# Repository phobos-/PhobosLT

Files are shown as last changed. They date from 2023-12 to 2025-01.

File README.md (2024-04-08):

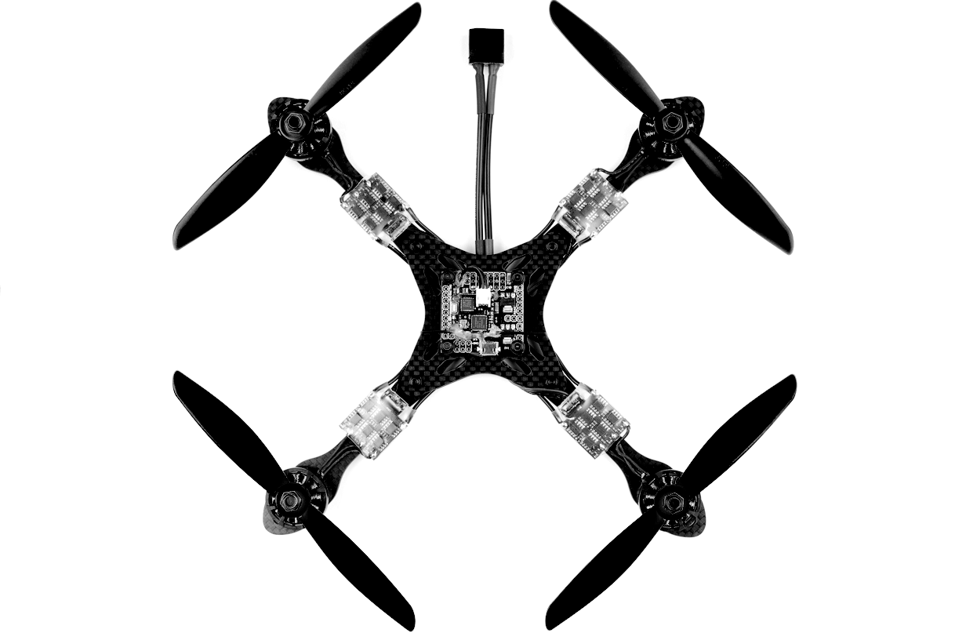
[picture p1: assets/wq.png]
PhobosLT
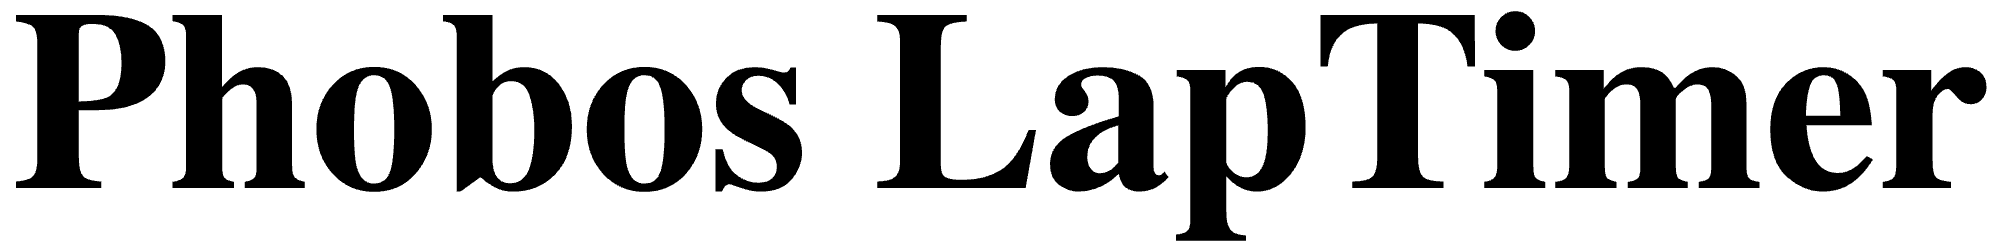
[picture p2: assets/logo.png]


 
# Support PhobosLT
**Affordable FPV single node Race Timing solution**

If you like this project you can support it by contributing to the codebase, testing and giving feedback, sharing new ideas and helping spread the PhobosLT gospel. You can also consider buying me a bubble tea or a beer, it will fuel me to make the project better!



# About

Phobos LapTimer (or PhobosLT) is a simple but mighty lap timing solution for 5.8GHz FPV pilots. It is designed for personal use and with small drones in mind (2 inch or less), but there is nothing against running it with bigger drones! It is a small standalone device that is self powered and communicates over WiFi with a phone, tablet or laptop. The goal of the project is to have a simple to use and small device that can be used anywhere whenever you want to do a whoop race practice session in your living room or at a local training venue with friends with no fuss.
Parts of the code are based on [RotorHazard](https://github.com/RotorHazard/RotorHazard) and [ExpressLRS](https://github.com/ExpressLRS/ExpressLRS). Big kudos to people behind these organizations, they are doing A LOT for the community and are shaping the future of FPV. If you don't know these projects yet and have some time, do check them out!

### Features

PhobosLT has the following features:
- Single node timing of 5.8GHz Analog, HDZero, Walksnail systems.
- Voice callouts, optionally including pilot name.
- Real time RSSI readout and calibration - allows for timing even in small spaces like a 16m^2 or 200 ft^2 room.
- 2 lap consecutive and 3 lap consecutive times and optional readouts on the fly (specially developed for [RaceGOW](https://www.racegow.com/)).
- Viewable lap history.
- Ability to set a minimal measurable lap time to avoid false positives.
- Configurable low voltage alarm.
- Small size, easy to build.
- Relatively cheap.
- No extra apps needed, self sufficient solution.

Future development plans:
- Flashing via WiFi or via web configurator.
- Custom hardware to minimize soldering.
- Integration with ExpressLRS and goggle VRXs to forward lap times to the OSD.
- Integration with RotorHazard to measure split times.
- Supporting multiple pilots at the same time at a cost of lower accuracy.

### How it works

The core of the project is an ESP32 board + an RX5808 module. ESP acts as a web server which serves a simple web page with all the configurations. Any device with WiFi connectivity and a web browser can be used to connect to it, configure the timer and measure lap times.

The lap timing happens by measuring the RSSI over time, filtering it and checking for peaks in the RSSI as the closer the drone is to the timer the higher the RSSI. Based on that we set up an `Enter RSSI` and `Exit RSSI` thresholds, that tell us when to cut a peak. The time between the enter and exit RSSI is then used to measure the time between the last peak and the current peak which is a lap.

Communication with the client happens over WiFi. The ESP32 sets up an access point and the client connects to it. RSSI is transmitted over a websocket to draw the RSSI graph in real time. Configuration, user interactions and events (like starting the timer, stopping, reporting a lap time) are done using rest calls.

The browser is leveraged to emit sounds or call out lap times using [articulate.js](https://github.com/acoti/articulate.js) library, but an optional (but recommended) beeper can be installed to the timer to also emit a sound every time a peak is detected or to alert e.g. when the timer battery voltage is low. 

# How to build one

### Hardware

To build a Phobos LapTimer you will need:
- An ESP32 breakout board, preferably with USB. The codebase is plug and play with `LilyGo T-ENERGY` which has a built in 1s 18650 Li-Ion cell slot and voltage sensing circuit out of the box. Supported boards:
    - LilyGo T-ENERGY - recommended.
    - LilyGo T-CELL - more expensive than the one above but has a charging circuit.
    - ESP32-DevKit - bare bones but cheap.
- An RX5808 VRx module with [SPI mod](https://sheaivey.github.io/rx5808-pro-diversity/docs/rx5808-spi-mod.html).
- A voltage supply of any sort - a battery, a powerbank, etc. It will depend on the ESP32 module used.
- (Optional) An LED of any color (+ a matching resistor to manage current).
- (Optional) A 3v3 to 5v buzzer WITH a generator (so active and not passive).

To connect the RX5808 to the ESP32 use below pinout table. Please note that +5v pin on the RX5808 should be connected to a 3v3 source to undervolt the RX5808 to get a better RSSI resolution and to help with cooling:
| ESP32 PIN | RX5880 |
| :--- |:---|
| 33 | RSSI |
| GND | GND |
| 19 | CH1 |
| 22 | CH2 |
| 23 | CH3 |
| 3V3 | +5V |

Optional but recommended LED, Buzzer and Battery voltage input pinout:
| ESP32 PIN | Peripheral |
| :--- |:---|
| 21 | LED anode (+) |
| 27 | Buzzer positive (+) |
| 35 | VBAT input MAX 3.3v (the code assumes a 1/2 voltage divider with a 1s Li-Ion  cell) |

You can find a connection diagram of the peripherals below. **For T-Energy and T-Cell you just need to connect the RX5808 and a buzzer.**

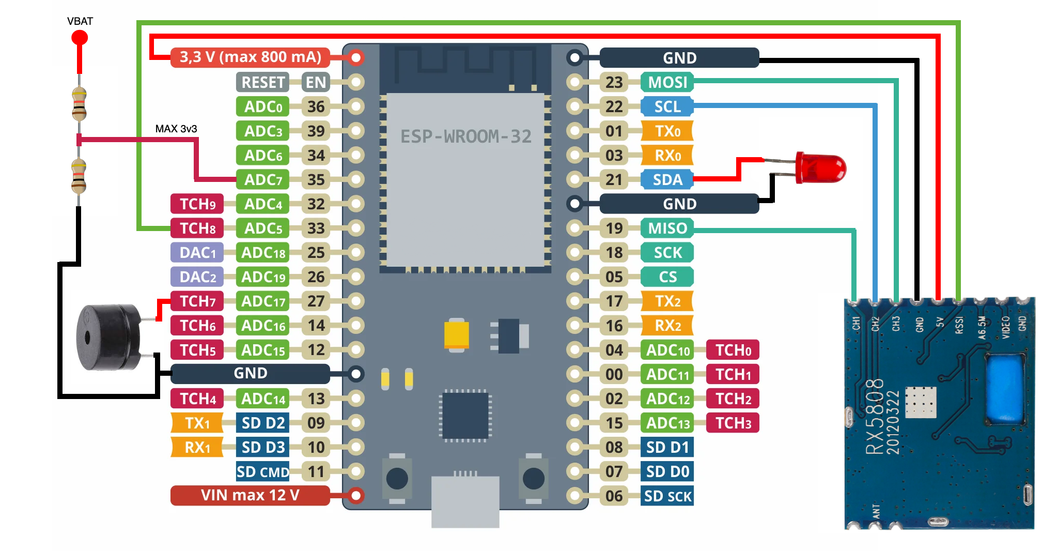
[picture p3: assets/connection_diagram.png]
Connection


Alternatively you can ask the community to build a timer for you. Ask around on discord!

### Firmware

Currently building the firmware happens via Visual Studio Code. The toolchain setup is exactly the same as for ExpressLRS, so if you already have an ExpressLRS toolchain set up and running, you should be good. The requirements to build the firmware are as follows:
- Visual Studio Code.
- PlatformIO.
- Git.

#### Toolchain setup

Perform these steps to set the toolchain up on your computer:
1. Download and install [vscode](https://code.visualstudio.com/).
2. Open vscode, and click on the `Extensions` icon in the toolbar on the right (see [Managing Extensions](https://code.visualstudio.com/docs/editor/extension-marketplace)).
3. In the search box, enter platformio, and install the extension (see the `pio install` [documentation](https://platformio.org/install/ide?install=vscode)).
4. Install [git](https://github.com/git-guides/install-git).

The last step before you can build the firmware is to clone this repository to your computer:
- In VSCode open the command palette (using `Cmd+Shift+P` on MacOS or `Ctrl+Shift+P` on Windows)
- Enter `Git: Clone`.
- Click it.
- Then, enter PhobosLT repo URL (can be found on top of the github page under the `Clone` button).
- Choose a folder where you want your copy of the repository to be located.

#### Building

To build the firmware, click the `PlatformIO` icon in the toolbar on the left, which will show the list of tasks. Now, select `Project Tasks`, expand `PhobosLT` -> `General` and select `Build`. You should see the result in the terminal after a few seconds (`Success`).

#### Flashing

Before attemtping to flash ensure there is a connection between the ESP32 and the computer via USB. Flashing is a two step process. First we need to flash the firmware, then the static file system image to the ESP32.

##### Step 1

To flash the firmware, click the `PlatformIO` icon in the toolbar on the left, which will show the list of tasks. Now, select `Project Tasks`, expand `PhobosLT` -> `General` and select `Upload`. You should see the result in the terminal (`Success`). Next, go to step 2.

##### Step 2

Select `Project Tasks`, expand `PhobosLT` -> `Platform` and select `Upload Filesystem Image`. Wait for the result in the terminal saying `Success`. That's it! Your timer is ready to use.

If something went wrong - please check the Terminal, too. It will contain at least a hint of what the issue is. Please ask the community for further help on discord!

#### 3D printed cases
[ESP-WROOM-32 case by porlock](https://makerworld.com/en/models/400720)

# Usage

This section is going to describe the usage and configuration of the timer. The app consists of 3 pages and is very easy to use!

### First connect

1. Turn on the timer, you should hear a short and a long beep.
2. Turn on your device and turn on WiFi.
3. Wait for it to discover a WiFi access point starting with `PhobosLT_xxxx`.
4. Click on it and type the password: `phoboslt`.
5. It should connect and open a browser window with the app for you. If it's not happening, open the browser and type `20.0.0.1`.
6. Voila!

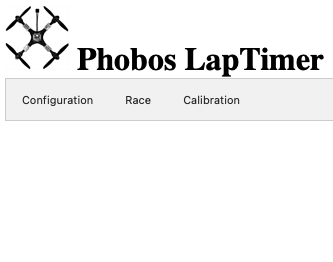
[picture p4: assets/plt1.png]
Homepage


### Configuration

To configure the timer you need to click on the `Configuration` button. You should be greeted with a screen similar to this:

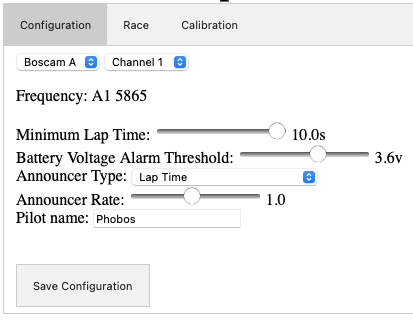
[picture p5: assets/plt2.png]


Below you can find all the config parameters and their description:

**Channel and Band** - set to the same Band and Channel as your drone. Supported Bands - A, B, E, Fatshark, RaceBand and LowBand, 8 channel each.
**Frequency** - this is a static field that will display the frequency based on the set Band and Channel.
**Minimum Lap Time** - you can set a minimum lap time that can be timed. This avoids false positives when you crash in the start gate, or when your track is very tight and you fly in close proximity to the timer multiple times during one lap.
**Battery Voltage Alarm Threshold** - sets a battery voltage alarm that will trigger once the desired voltage is reached. The range is between 2.5-4.2v.
**Announcer Type** - you have a few options on how you want your timer to report lap times:
- `None` is no sound at all.
- `Beep` will just emit a short beep on crossing to let you know it registered a lap.
- `Lap Time` will announce the lap time (including your pilot name if the **Pilot name** field is filled).
- `Two Consecutive Lap Time` will announce the two consecutive lap time.
- `Three Consecutive Lap Time` will announce the three consecutive lap time.

**Announcer Rate** - controls the speed of the announcer reading the lap time.
**Pilot Name** - when filled it will include pilot name when reading the times, e.g. `Pilot1 23.45`. It is useful when there is more than just one timer running at the same time. When practicing alone leave it empty.

**NOTE: Once configured make sure to save the configuration by clicking on the `Save Configuration` button, otherwise the changes will not take effect.**

### Calibration

Calibartion is a very important step and it needs to be done properly to ensure the timing happens correctly and every lap is counted by the timer.

To perform the calibration click on the `Calibration` button. You should be presented with two sliders and a graph representing the RSSI over time. You can think of RSSI as an inverse of the distance between the drone and the timer. The higher the RSSI the shorter the distance.

A node can be either `Crossing` or `Clear`. If a node is `Clear`, the timer believes a drone is not near the timer because the RSSI is low. If it is `Crossing`, the timer believes a drone is passing by the timer because the RSSI is high. A lap pass will be recorded once the `Crossing` is finished and the RSSI returns to `Clear` zone. We calibrate that by setting `Enter` and `Exit` RSSI thresholds.

A well calibrated timer will show the lap time when we have only one crossing when drone is the closest to the timer, e.g.:

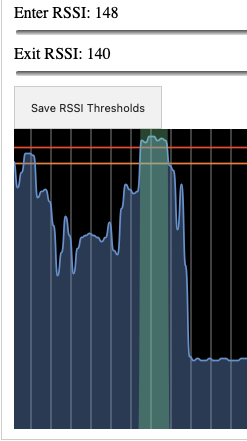
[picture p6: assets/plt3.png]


`Crossing` will always be marked in dark green, while `Clear` will be colored in blue.

To come up with good initial values for `Enter` and `Exit` RSSI perform these steps:
1. Turn on the timer and your drone, set it to the desired VTx power, wait 30 seconds for the VTx to reach its running temperature.
2. Place the drone at a distance of slightly more than one gate above the timer. 
3. Note the RSSI, deduct 2-5 points to be safe - that should be your `Enter RSSI`. 
4. Deduct another 8-10 points and set it as your `Exit RSSI`. 
5. **Click on `Save RSSI Thresholds` - otherwise the changes will not take effect.**

When flying with other pilots the RSSI readings might be lower due to all the noise generated by other VTxs on adjecent channels. A good practice is to lower both thresholds by a few points when flying with other pilots in the air.

### Race and lap management

The Race screen will allow you to start or stop a race and view and clear your lap times. Once clicked on the `Race` button a screen will change to this:

Race

Functions of the buttons:
- `Start Race` - click it to to start the countdown and signal the timer to start counting laps. 
- `Stop Race` - press it when you want to stop counting new laps. It does not clear the laps collected so far.
- `Clear Laps` - clears the laps on the screen, can be done when the race is running as well.

Once you run a few laps the screen will populate with lap times:

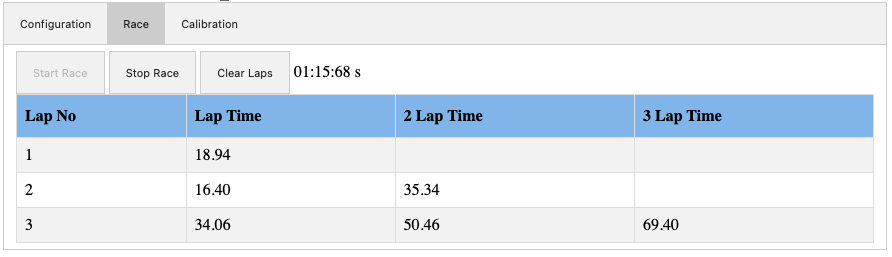
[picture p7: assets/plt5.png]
Race FInished


# Community

Join our [Discord](https://discord.gg/D3MgfvsnAw) channel for support and questions or just to hang out! Everyone is welcome!

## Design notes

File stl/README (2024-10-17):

I MODIFIED THIS VERSION SO YOU CAN PUT THE RECEIVER ON THE SIDE AND USE 6X3mm MAGNETS  
https://www.printables.com/model/88283-lilygo-t-energy-case

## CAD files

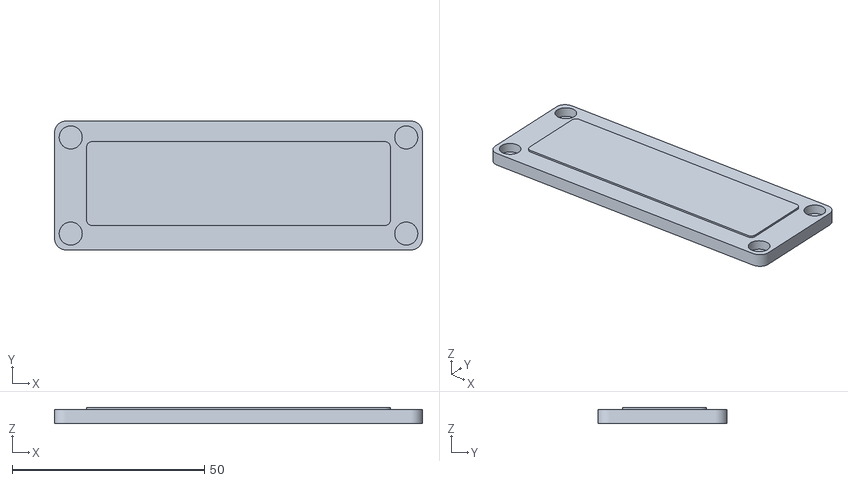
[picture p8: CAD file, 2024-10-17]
stl/T-Energy Thicc Bottom.stl
95.7 x 33.5 x 4.20

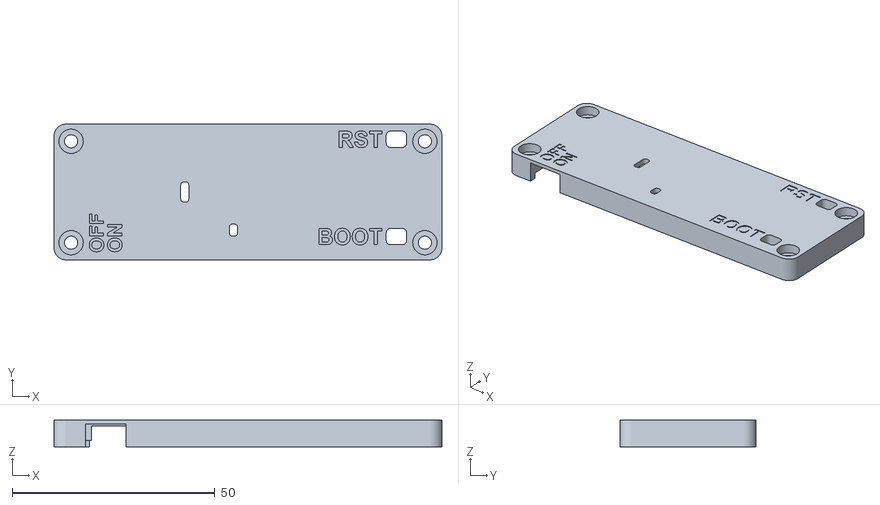
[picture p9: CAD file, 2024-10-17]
stl/T-Energy Thicc Top.stl
95.7 x 33.5 x 6.60

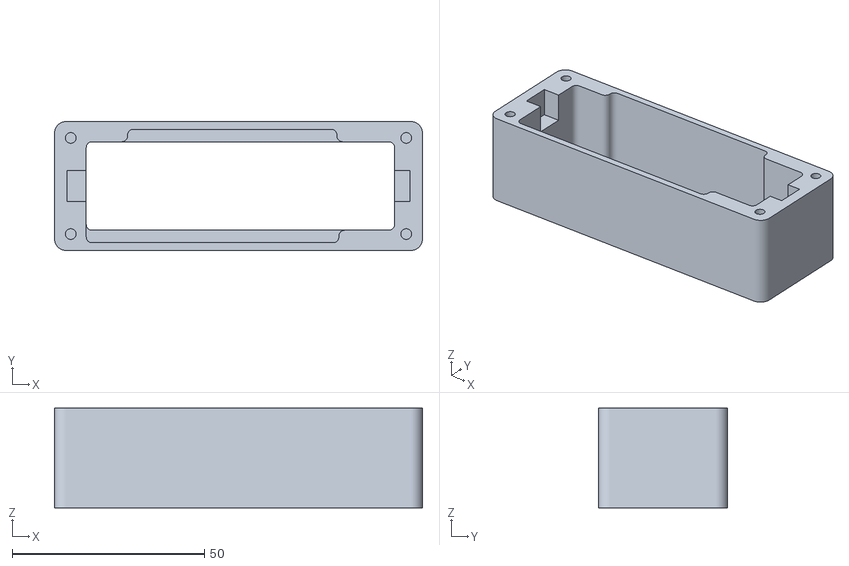
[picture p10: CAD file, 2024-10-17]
stl/T-Energy Thicc Middle.stl
95.7 x 33.5 x 26.0

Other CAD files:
stl/T-Go Energy Thicc v13.f3d

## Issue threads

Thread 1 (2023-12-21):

Unable to build firmware

caixiaohai0, 2023-12-21:
Processing PhobosLT (framework: arduino; platform: espressif32@5.2.0; board: esp32dev)
-----------------------------------------------------------------------------------------------------------------------------------------------------------------------------------------Verbose mode can be enabled via `-v, --verbose` option
CONFIGURATION: https://docs.platformio.org/page/boards/espressif32/esp32dev.html
PLATFORM: Espressif 32 (5.2.0) > Espressif ESP32 Dev Module
HARDWARE: ESP32 240MHz, 320KB RAM, 4MB Flash
DEBUG: Current (cmsis-dap) External (cmsis-dap, esp-bridge, esp-prog, iot-bus-jtag, jlink, minimodule, olimex-arm-usb-ocd, olimex-arm-usb-ocd-h, olimex-arm-usb-tiny-h, olimex-jtag-tiny, tumpa)
PACKAGES:
 - framework-arduinoespressif32 @ 3.20005.220925 (2.0.5)
 - tool-esptoolpy @ 1.40201.0 (4.2.1)
 - toolchain-xtensa-esp32 @ 8.4.0+2021r2-patch3
LDF: Library Dependency Finder -> https://bit.ly/configure-pio-ldf
LDF Modes: Finder ~ chain, Compatibility ~ soft
Found 44 compatible libraries
Scanning dependencies...
Dependency Graph
|-- ESPAsyncWebServer-esphome @ 3.0.0
|-- ArduinoJson @ 6.19.4
|-- DEBUG
|-- LED
|-- WEBSERVER
Building in release mode
Compiling .pio\build\PhobosLT\liba74\AsyncTCP-esphome\AsyncTCP.cpp.o
.pio/libdeps/PhobosLT/AsyncTCP-esphome/src/AsyncTCP.cpp:753:2: error: #else without #if
 #else
  ^~~~
.pio/libdeps/PhobosLT/AsyncTCP-esphome/src/AsyncTCP.cpp:755:2: error: #endif without #if
 #endif
  ^~~~~
.pio/libdeps/PhobosLT/AsyncTCP-esphome/src/AsyncTCP.cpp:1020: error: unterminated #if
 #if LWIP_IPV4 && LWIP_IPV6

.pio/libdeps/PhobosLT/AsyncTCP-esphome/src/AsyncTCP.cpp: In member function 'bool AsyncClient::connect(const char*, uint16_t)':
.pio/libdeps/PhobosLT/AsyncTCP-esphome/src/AsyncTCP.cpp:754:39: error: 'ip_addr_t' {aka 'struct ip_addr'} has no member named 'addr'; did you mean 'u_addr'?
         return connect(IPAddress(addr.addr), port);
                                       ^~~~
                                       u_addr
Compiling .pio\build\PhobosLT\FrameworkArduino\libb64\cdecode.c.o
Compiling .pio\build\PhobosLT\FrameworkArduino\libb64\cencode.c.o
Compiling .pio\build\PhobosLT\FrameworkArduino\main.cpp.o
Compiling .pio\build\PhobosLT\FrameworkArduino\stdlib_noniso.c.o
Compiling .pio\build\PhobosLT\FrameworkArduino\wiring_pulse.c.o
Compiling .pio\build\PhobosLT\FrameworkArduino\wiring_shift.c.o
*** [.pio\build\PhobosLT\liba74\AsyncTCP-esphome\AsyncTCP.cpp.o] Error 1
============================================================================== [FAILED] Took 11.06 seconds ==============================================================================

caixiaohai0, 2023-12-21:
When I try to build the firmware, it shows the error above, what step am I doing wrong?

phobos-, 2023-12-25:
Hey, thank you for spotting this. The problem was with AsyncTCP version that recently has been bumped to 2.1.0. I added an explicit dependency on 2.0.1 to fix the problem.

Here is the original issue:
https://github.com/esphome/issues/issues/5258

Here is my fix:
https://github.com/phobos-/PhobosLT/commit/ebac87fa705b17e784c25d2093556ea0d34bc4df

caixiaohai0, 2023-12-25:
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
The Discord invitation has expired, can you update it again?

phobos-, 2023-12-25:
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

done

Closed 2023-12-25.

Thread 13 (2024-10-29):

TTGO Cell, no download mode?

DexterGre, 2024-10-29:
Verbose mode can be enabled via `-v, --verbose` option
CONFIGURATION: https://docs.platformio.org/page/boards/espressif32/esp32dev.html
PLATFORM: Espressif 32 (6.9.0) > Espressif ESP32 Dev Module
HARDWARE: ESP32 240MHz, 320KB RAM, 4MB Flash
DEBUG: Current (cmsis-dap) External (cmsis-dap, esp-bridge, esp-prog, iot-bus-jtag, jlink, minimodule, olimex-arm-usb-ocd, olimex-arm-usb-ocd-h, olimex-arm-usb-tiny-h, olimex-jtag-tiny, tumpa)
PACKAGES:
 - framework-arduinoespressif32 @ 3.20017.0 (2.0.17)
 - tool-esptoolpy @ 1.40501.0 (4.5.1)
 - tool-mkfatfs @ 2.0.1
 - tool-mklittlefs @ 1.203.210628 (2.3)
 - tool-mkspiffs @ 2.230.0 (2.30)
 - toolchain-xtensa-esp32 @ 8.4.0+2021r2-patch5
LDF: Library Dependency Finder -> https://bit.ly/configure-pio-ldf
LDF Modes: Finder ~ chain, Compatibility ~ soft
Found 45 compatible libraries
Scanning dependencies...
Dependency Graph
|-- ESPAsyncWebServer-esphome @ 3.2.2
|-- ArduinoJson @ 7.2.0
|-- AsyncTCP-esphome @ 2.1.4
|-- DEBUG
|-- LED
|-- WEBSERVER
Building in release mode
Retrieving maximum program size .pio\build\PhobosLT\firmware.elf
Checking size .pio\build\PhobosLT\firmware.elf
Advanced Memory Usage is available via "PlatformIO Home > Project Inspect"
RAM:   [=         ]  14.8% (used 48384 bytes from 327680 bytes)
Flash: [=======   ]  70.0% (used 917993 bytes from 1310720 bytes)
Configuring upload protocol...
AVAILABLE: cmsis-dap, esp-bridge, esp-prog, espota, esptool, iot-bus-jtag, jlink, minimodule, olimex-arm-usb-ocd, olimex-arm-usb-ocd-h, olimex-arm-usb-tiny-h, olimex-jtag-tiny, tumpa
CURRENT: upload_protocol = esptool
Looking for upload port...
Auto-detected: COM6
Uploading .pio\build\PhobosLT\firmware.bin
esptool.py v4.5.1
Serial port COM6
Connecting......................................

A fatal error occurred: Failed to connect to ESP32: Wrong boot mode detected (0x17)! The chip needs to be in download mode.
For troubleshooting steps visit: https://docs.espressif.com/projects/esptool/en/latest/troubleshooting.html
*** [upload] Error 2
========================================================================================= [FAILED] Took 17.21 seconds =========================================================================================

Environment    Status    Duration
-------------  --------  ------------
PhobosLT       FAILED    00:00:17.211
==================================================================================== 1 failed, 0 succeeded in 00:00:17.211 ====================================================================================

What do in have to press? Pressing RST didnt work. There is no boot buton on the TTGO T-CELL.

DexterGre, 2024-10-31:
my bad ... short GPIO0 with GND and then Press reset

Closed 2024-11-07.

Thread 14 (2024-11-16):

[BUG] Every 50th lap time is incorrect

Jaz7Mutant, 2024-11-16:
I've noticed that every 50th lap is approximately 1,000,000 seconds. You can see it in my run here.
[Phobos LapTimer.pdf](https://github.com/user-attachments/files/17787186/Phobos.LapTimer.pdf)

FernandoRangel, 2024-12-15:
> I've noticed that every 50th lap is approximately 1,000,000 seconds. You can see it in my run here. [Phobos LapTimer.pdf](https://github.com/user-attachments/files/17787186/Phobos.LapTimer.pdf)

I fixed it by changing this line
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

phobos-, 2025-01-13:
the fix is merged to master, closing this.

Closed 2025-01-13.

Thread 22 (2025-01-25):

SpeechSynthesis api doesn't work on mobile browser when it is not triggered directly by user

aikidistas, 2025-01-25:
Updated mobile browser policies disabled voice generated automatically by code without user input.
From now on we can't call SpeechSynthesis.speak directly from code that is not initiated by user click, like previously it was used by events.
Added "Enable voice" button which is calling articulate.js speak (which internally call SpeechSynthesis.speak.
Workaround pass text to speak to main code initiated by user with "enable voice" button.

Created pull request to fix this issue.
https://github.com/phobos-/PhobosLT/pull/21

phobos-, 2025-01-27:
Thank you! This is merged now, enjoy.

Closed 2025-01-27.

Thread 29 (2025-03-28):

Build failure due to package AsyncWebServer

orevron, 2025-03-28:
Trying to build the project (no matter which platform I'm trying to build for wether it is PhobosLT default of S3) I'm getting the same error as the following:

```
Processing ESP32S3 (framework: arduino; platform: espressif32@6.9.0; board: esp32-s3-devkitc-1)
---------------------------------------------------------------------------------------------------------------------------------------------------------------------------------------
Library Manager: Installing git+https://github.com/mkfrey/AsyncTCP#kconfig_queue_size
git version 2.39.5 (Apple Git-154)
Cloning into '/Users/oevron/.platformio/.cache/tmp/pkg-installing-ftwaudvs'...
remote: Enumerating objects: 23, done.
remote: Counting objects: 100% (23/23), done.
remote: Compressing objects: 100% (21/21), done.
remote: Total 23 (delta 0), reused 10 (delta 0), pack-reused 0 (from 0)
Receiving objects: 100% (23/23), 19.40 KiB | 19.40 MiB/s, done.
Library Manager: AsyncTCP@1.1.1+sha.7855e2c has been installed!
Library Manager: Installing mathieucarbou/ESPAsyncWebServer @ ^3.3.21
Unpacking  [####################################]  100%
Library Manager: ESPAsyncWebServer@3.6.0 has been installed!
Library Manager: Resolving dependencies...
Library Manager: Installing mathieucarbou/AsyncTCP @ ^3.3.2
Unpacking  [####################################]  100%
Library Manager: AsyncTCP@3.3.2 has been installed!
Library Manager: Installing bblanchon/ArduinoJson @ 7.2.0
Unpacking  [####################################]  100%
Library Manager: ArduinoJson@7.2.0 has been installed!
Library Manager: Installing ayushsharma82/ElegantOTA @ ^3.1.6
Unpacking  [####################################]  100%
Library Manager: ElegantOTA@3.1.7 has been installed!
Library Manager: Resolving dependencies...
Library Manager: Installing esp32async/ESPAsyncWebServer @ ^3.7.3
Unpacking  [####################################]  100%
Library Manager: ESPAsyncWebServer@3.7.4 has been installed!
Library Manager: Resolving dependencies...
Library Manager: Installing ESP32Async/AsyncTCP @ ^3.3.8
Unpacking  [####################################]  100%
Library Manager: AsyncTCP@3.3.8 has been installed!
Verbose mode can be enabled via `-v, --verbose` option
CONFIGURATION: https://docs.platformio.org/page/boards/espressif32/esp32-s3-devkitc-1.html
PLATFORM: Espressif 32 (6.9.0) > Espressif ESP32-S3-DevKitC-1-N8 (8 MB QD, No PSRAM)
HARDWARE: ESP32S3 240MHz, 320KB RAM, 8MB Flash
DEBUG: Current (esp-builtin) On-board (esp-builtin) External (cmsis-dap, esp-bridge, esp-prog, iot-bus-jtag, jlink, minimodule, olimex-arm-usb-ocd, olimex-arm-usb-ocd-h, olimex-arm-usb-tiny-h, olimex-jtag-tiny, tumpa)
PACKAGES:
 - framework-arduinoespressif32 @ 3.20017.241212+sha.dcc1105b
 - tool-esptoolpy @ 1.40501.0 (4.5.1)
 - toolchain-riscv32-esp @ 8.4.0+2021r2-patch5
 - toolchain-xtensa-esp32s3 @ 8.4.0+2021r2-patch5
LDF: Library Dependency Finder -> https://bit.ly/configure-pio-ldf
LDF Modes: Finder ~ chain, Compatibility ~ strict
Found 49 compatible libraries
Scanning dependencies...
Dependency Graph
|-- AsyncTCP @ 1.1.1+sha.7855e2c
|-- ESPAsyncWebServer @ 3.6.0
|-- ArduinoJson @ 7.2.0
|-- ElegantOTA @ 3.1.7
|-- DEBUG
|-- LED
|-- WEBSERVER
Building in release mode
Compiling .pio/build/ESP32S3/src/main.cpp.o
Building .pio/build/ESP32S3/bootloader.bin
Generating partitions .pio/build/ESP32S3/partitions.bin
esptool.py v4.5.1
Creating esp32s3 image...
Merged 1 ELF section
Successfully created esp32s3 image.
Compiling .pio/build/ESP32S3/lib44a/AsyncTCP@src-08944e2265d70e4bf415e06a141519af/AsyncTCP.cpp.o
Compiling .pio/build/ESP32S3/lib73a/FS/FS.cpp.o
Compiling .pio/build/ESP32S3/lib73a/FS/vfs_api.cpp.o
Compiling .pio/build/ESP32S3/lib57d/WiFi/WiFi.cpp.o
Compiling .pio/build/ESP32S3/lib57d/WiFi/WiFiAP.cpp.o
Compiling .pio/build/ESP32S3/lib57d/WiFi/WiFiClient.cpp.o
Compiling .pio/build/ESP32S3/lib57d/WiFi/WiFiGeneric.cpp.o
Compiling .pio/build/ESP32S3/lib57d/WiFi/WiFiMulti.cpp.o
Compiling .pio/build/ESP32S3/lib57d/WiFi/WiFiSTA.cpp.o
Compiling .pio/build/ESP32S3/lib57d/WiFi/WiFiScan.cpp.o
Compiling .pio/build/ESP32S3/lib57d/WiFi/WiFiServer.cpp.o
In file included from lib/WEBSERVER/webserver.h:1,
                 from src/main.cpp:3:
.pio/libdeps/ESP32S3/ESPAsyncWebServer/src/ESPAsyncWebServer.h: In member function 'tcp_state AsyncWebServer::state() const':
.pio/libdeps/ESP32S3/ESPAsyncWebServer/src/ESPAsyncWebServer.h:1107:50: error: passing 'const AsyncServer' as 'this' argument discards qualifiers [-fpermissive]
     return static_cast<tcp_state>(_server.status());
                                                  ^
In file included from .pio/libdeps/ESP32S3/ESPAsyncWebServer/src/ESPAsyncWebServer.h:19,
                 from lib/WEBSERVER/webserver.h:1,
                 from src/main.cpp:3:
.pio/libdeps/ESP32S3/AsyncTCP@src-08944e2265d70e4bf415e06a141519af/src/AsyncTCP.h:202:13: note:   in call to 'uint8_t AsyncServer::status()'
     uint8_t status();
             ^~~~~~
Archiving .pio/build/ESP32S3/lib44a/libAsyncTCP@src-08944e2265d70e4bf415e06a141519af.a
Compiling .pio/build/ESP32S3/lib57d/WiFi/WiFiUdp.cpp.o
Archiving .pio/build/ESP32S3/lib73a/libFS.a
*** [.pio/build/ESP32S3/src/main.cpp.o] Error 1
Indexing .pio/build/ESP32S3/lib44a/libAsyncTCP@src-08944e2265d70e4bf415e06a141519af.a
Indexing .pio/build/ESP32S3/lib73a/libFS.a
============================================================================= [FAILED] Took 6.81 seconds =============================================================================

Environment    Status    Duration
-------------  --------  ------------
ESP32S3        FAILED    00:00:06.809
======================================================================== 1 failed, 0 succeeded in 00:00:06.809 ========================================================================
```

Tried to resolve this issue by casting the return value of the `tcp_state` function in the package code, build was successful but then a crash happen in runtime when ever a client is connected to the hotspot.

Can you help me resolve this issue?

Thanks!

DavidJJ, 2025-03-30:
I added:

'-fpermissive' to the build flags in targets/PhobosLT.ini

and it built but this error should be fixed.  not sure if it is an issue with PhobosLT or with upstream library

mupchu, 2025-04-12:
This is still an issue:

Compiling .pio\build\PhobosLT\libfe4\ESPAsyncWebServer\AsyncEventSource.cpp.o
Compiling .pio\build\PhobosLT\libfe4\ESPAsyncWebServer\AsyncJson.cpp.o
*** [.pio\build\PhobosLT\src\main.cpp.o] Error 1
In file included from .pio/libdeps/PhobosLT/ESPAsyncWebServer/src/AsyncEventSource.h:33,
                 from .pio/libdeps/PhobosLT/ESPAsyncWebServer/src/AsyncEventSource.cpp:8:
.pio/libdeps/PhobosLT/ESPAsyncWebServer/src/ESPAsyncWebServer.h: In member function 'tcp_state AsyncWebServer::state() const':
.pio/libdeps/PhobosLT/ESPAsyncWebServer/src/ESPAsyncWebServer.h:1107:50: error: passing 'const AsyncServer' as 'this' argument discards qualifiers [-fpermissive]
     return static_cast<tcp_state>(_server.status());
                                                  ^
In file included from .pio/libdeps/PhobosLT/ESPAsyncWebServer/src/AsyncEventSource.h:10,
                 from .pio/libdeps/PhobosLT/ESPAsyncWebServer/src/AsyncEventSource.cpp:8:
.pio/libdeps/PhobosLT/AsyncTCP@src-08944e2265d70e4bf415e06a141519af/src/AsyncTCP.h:202:13: note:   in call to 'uint8_t AsyncServer::status()'
     uint8_t status();
             ^~~~~~
*** [.pio\build\PhobosLT\libfe4\ESPAsyncWebServer\AsyncEventSource.cpp.o] Error 1
In file included from .pio/libdeps/PhobosLT/ESPAsyncWebServer/src/AsyncJson.h:17,
                 from .pio/libdeps/PhobosLT/ESPAsyncWebServer/src/AsyncJson.cpp:4:
.pio/libdeps/PhobosLT/ESPAsyncWebServer/src/ESPAsyncWebServer.h: In member function 'tcp_state AsyncWebServer::state() const':
.pio/libdeps/PhobosLT/ESPAsyncWebServer/src/ESPAsyncWebServer.h:1107:50: error: passing 'const AsyncServer' as 'this' argument discards qualifiers [-fpermissive]
     return static_cast<tcp_state>(_server.status());
                                                  ^
In file included from .pio/libdeps/PhobosLT/ESPAsyncWebServer/src/ESPAsyncWebServer.h:19,
                 from .pio/libdeps/PhobosLT/ESPAsyncWebServer/src/AsyncJson.h:17,
                 from .pio/libdeps/PhobosLT/ESPAsyncWebServer/src/AsyncJson.cpp:4:
.pio/libdeps/PhobosLT/AsyncTCP@src-08944e2265d70e4bf415e06a141519af/src/AsyncTCP.h:202:13: note:   in call to 'uint8_t AsyncServer::status()'
     uint8_t status();
             ^~~~~~
*** [.pio\build\PhobosLT\libfe4\ESPAsyncWebServer\AsyncJson.cpp.o] Error 1

weakwire, 2025-04-19:
facing the same issue

mupchu, 2025-04-19:
so anyone facing this issue, please see the discord to get help.  Answer to this problem can be found there, posting it here as well.

Statl3r — 4/13/2025 10:55 PM
No problem.
You need to adjust the ini-file which corresponds to your build-target - e.g. "PhobosLT.ini" for a original ESP32 (which is integrated in the popular ESP32-WROOM modules). The screenshot shows the modification. You may adapt the line 19 and in addition also line 13.

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

weakwire, 2025-04-20:
Thanks for that. I already tried and it compiles. however GET /events returns 404 and the implementation doesn't work. Is there a work around to it? I currently use a previous commit 5b580584e4bf9303e3f4fbc1d00f9c77ab5e00c3 that works for me.

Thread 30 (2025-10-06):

4 problems during building procedure

fisherhrussell-commits, 2025-10-06:
Hello, I'm seeing these errors,

Terminal messge:

In file included from lib/WEBSERVER/webserver.h:1,
                 from src/main.cpp:3:
.pio/libdeps/PhobosLT/ESPAsyncWebServer/src/ESPAsyncWebServer.h: In member function 'tcp_state AsyncWebServer::state() const':
.pio/libdeps/PhobosLT/ESPAsyncWebServer/src/ESPAsyncWebServer.h:1126:3: warning: no return statement in function returning non-void [-Wreturn-type]
   }
   ^
Compiling .pio\build\PhobosLT\lib894\WiFi\WiFiUdp.cpp.o
Archiving .pio\build\PhobosLT\lib08e\libAsyncTCP@src-08944e2265d70e4bf415e06a141519af.a
In file included from src/main.cpp:3:
lib/WEBSERVER/webserver.h: At global scope:
lib/WEBSERVER/webserver.h:26:5: error: 'wifi_mode_t' does not name a type; did you mean 'uart_mode_t'?
     wifi_mode_t wifiMode = WIFI_OFF;
     ^~~~~~~~~~~
     uart_mode_t
lib/WEBSERVER/webserver.h:27:5: error: 'wl_status_t' does not name a type; did you mean 'mbstate_t'?
     wl_status_t lastStatus = WL_IDLE_STATUS;
     ^~~~~~~~~~~
     mbstate_t
lib/WEBSERVER/webserver.h:28:14: error: 'wifi_mode_t' does not name a type; did you mean 'uart_mode_t'?
     volatile wifi_mode_t changeMode = WIFI_OFF;
              ^~~~~~~~~~~
              uart_mode_t
Archiving .pio\build\PhobosLT\lib50e\libFS.a
Compiling .pio\build\PhobosLT\libede\WebServer\Parsing.cpp.o
*** [.pio\build\PhobosLT\src\main.cpp.o] Error 1
================================================================= [FAILED] Took 7.44 seconds =================================================================

Environment    Status    Duration
-------------  --------  ------------
PhobosLT       FAILED    00:00:07.443
============================================================ 1 failed, 0 succeeded in 00:00:07.443 ============================================================

Each of the problems are:

'wifi_mode_t' does not name a type; did you mean 'uart_mode_t'?
identifier "WIFI_OFF" is undefined
'wl_status_t' does not name a type; did you mean 'mbstate_t'?
identifier "wl_status_t" is undefined
identifier "WL_IDLE_STATUS" is undefined
'wifi_mode_t' does not name a type; did you mean 'uart_mode_t'?
identifier "WIFI_OFF" is undefined
no return statement in function returning non-void [-Wreturn-type]

I don't know where to begin.

fisherhrussell-commits, 2025-10-06:
I found the answer to my problem on the Discord server. https://cdn.discordapp.com/attachments/1180943898080718888/1386626382049841192/image.png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

https://cdn.discordapp.com/attachments/1180943898080718888/1386626382288785479/image.png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

Closed 2025-10-06.

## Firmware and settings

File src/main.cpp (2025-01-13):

#include "debug.h"
#include "led.h"
#include "webserver.h"
#include <ElegantOTA.h>

static RX5808 rx(PIN_RX5808_RSSI, PIN_RX5808_DATA, PIN_RX5808_SELECT, PIN_RX5808_CLOCK);
static Config config;
static Webserver ws;
static Buzzer buzzer;
static Led led;
static LapTimer timer;
static BatteryMonitor monitor;

static TaskHandle_t xTimerTask = NULL;

static void parallelTask(void *pvArgs) {
    for (;;) {
        uint32_t currentTimeMs = millis();
        buzzer.handleBuzzer(currentTimeMs);
        led.handleLed(currentTimeMs);
        ws.handleWebUpdate(currentTimeMs);
        config.handleEeprom(currentTimeMs);
        rx.handleFrequencyChange(currentTimeMs, config.getFrequency());
        monitor.checkBatteryState(currentTimeMs, config.getAlarmThreshold());
        buzzer.handleBuzzer(currentTimeMs);
        led.handleLed(currentTimeMs);
    }
}

static void initParallelTask() {
    disableCore0WDT();
    xTaskCreatePinnedToCore(parallelTask, "parallelTask", 3000, NULL, 0, &xTimerTask, 0);
}

void setup() {
    DEBUG_INIT;
    config.init();
    rx.init();
    buzzer.init(PIN_BUZZER, BUZZER_INVERTED);
    led.init(PIN_LED, false);
    timer.init(&config, &rx, &buzzer, &led);
    monitor.init(PIN_VBAT, VBAT_SCALE, VBAT_ADD, &buzzer, &led);
    ws.init(&config, &timer, &monitor, &buzzer, &led);
    led.on(400);
    buzzer.beep(200);
    initParallelTask();
}

void loop() {
    uint32_t currentTimeMs = millis();
    timer.handleLapTimerUpdate(currentTimeMs);
    ElegantOTA.loop();
}

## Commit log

2024-04-08 Case by porlock
    * Update README.md
    added 3D printer cases section
    * Update README.md
    * Update README.md
2024-05-03 add support for esp32 c3 (#3)
2024-10-14 Performance improve and new target ESP32-S3 (#4)
    * Add ESP32-S3 Support
    * adjust some web interface
    * formatting
    * remove height for icon
    * Set CPU frequency of C3 and S3
    * performance improvements
2024-10-17 [FIX] Fix esp32 webserver 404 error! (#9)
2024-10-17 added stl files for the tt-energy (#10)
    * Add files via upload
    modified stl based on this https://www.printables.com/model/88283-lilygo-t-energy-case , so you can put the receiver on the side of the tt energy, i use the board whitout the pins and soldered direct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
    * Create stl
    * Delete stl
    * Create README
    * Add files via upload
    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
    [T-Energy Thicc Bottom.stl, T-Energy Thicc Middle.stl, T-Energy Thicc Top.stl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]
2025-01-13 Web UI improve + OTA Support (#8)
    * Web UI improve
    1. make UI more colorful
    2. add Hole Shot
    * 1. make UI more colorful
    2. add Hole Shot
    * fix buzzer issue
    * remove bottom margin
    * add ota support
    * Fix auto reboot after flash
    * sync with main branch
    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
    [main.cpp]
2025-05-04 Battery voltage display and holeshot timing (#24)
    * Newline for gitignore
    * Added battery voltage to configuration tab
    * Added backend holeshot tracking
    * Added holeshot voice callout
    * Resetting race when stop race clicked
    * Removed unnecessary defaults
    * Random starting time
    * Improved voice callout for start in less than five
    * Ability to disable low battery alarm by setting threshold to 0
    * Doubled maximum allowable min lap time

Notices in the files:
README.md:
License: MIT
